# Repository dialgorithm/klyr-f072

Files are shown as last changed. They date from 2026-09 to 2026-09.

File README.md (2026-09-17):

<h1 align="center">
  klyr f072
  <br>
</h1>

<h4 align="center">
    STM32F072CBT6 dev board with usb c
</h4>

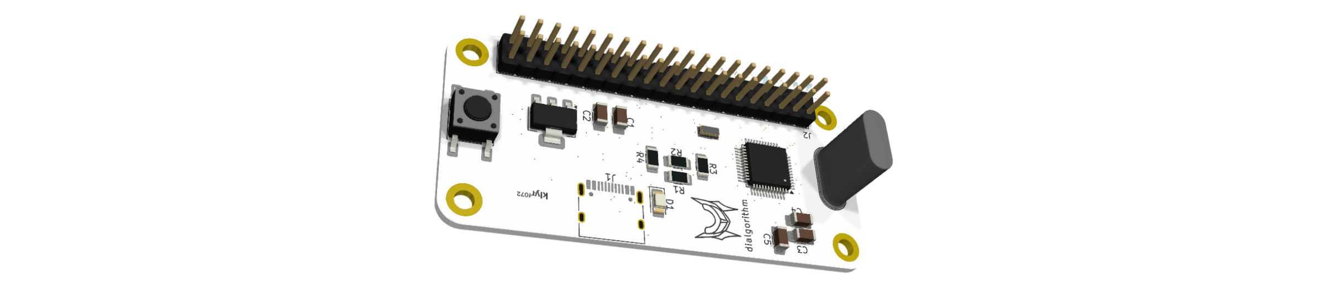
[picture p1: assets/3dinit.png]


## Schematics + PCB

| Schematic | PCB |
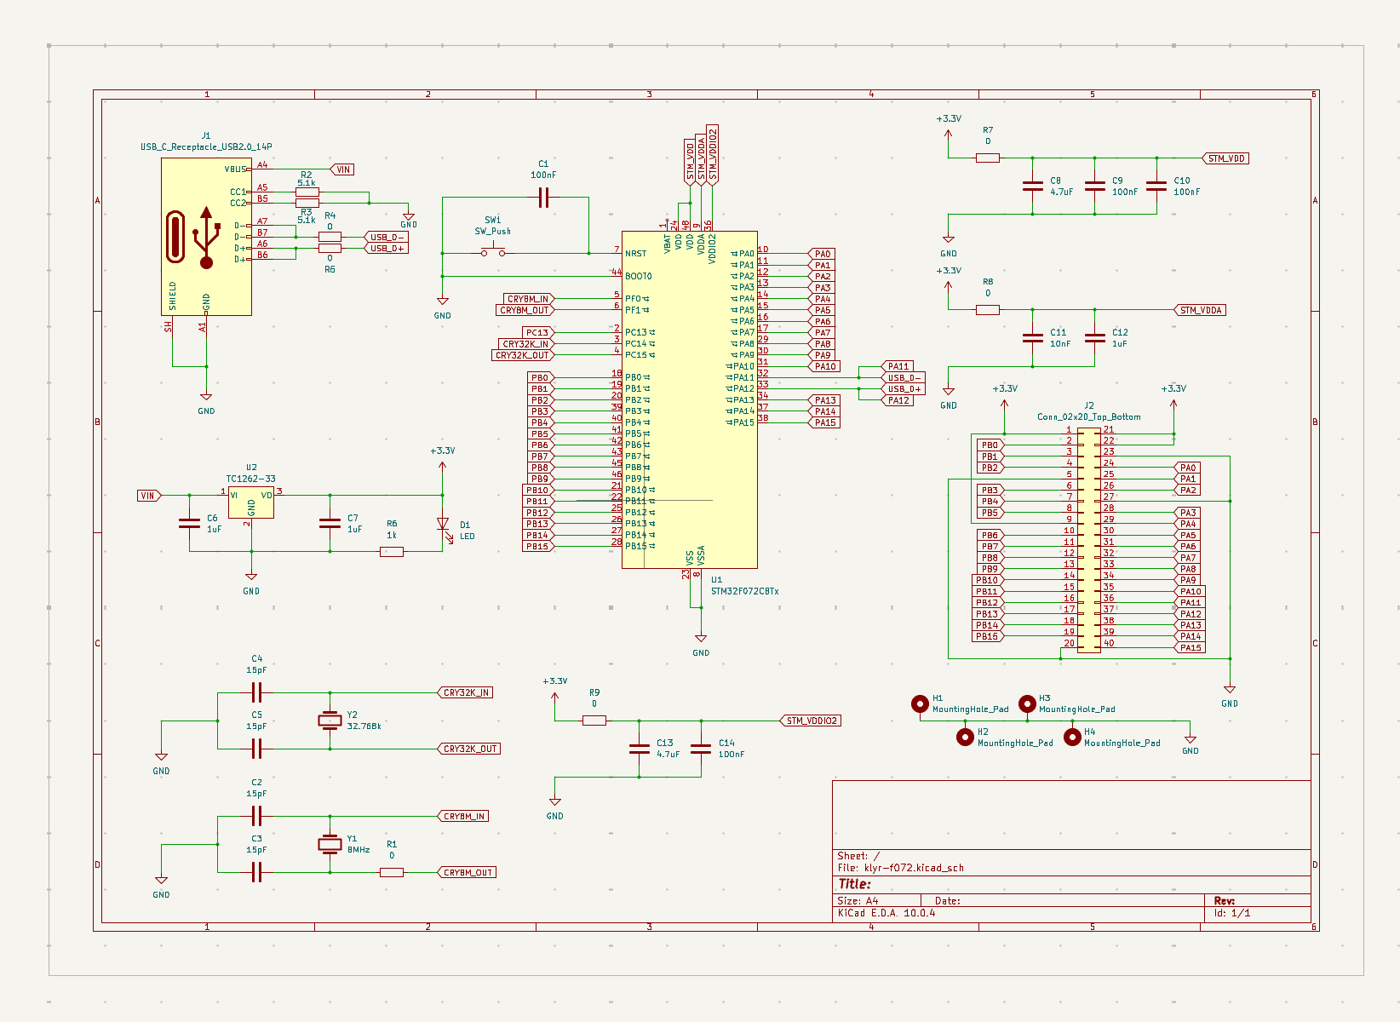
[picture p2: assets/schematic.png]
schematic
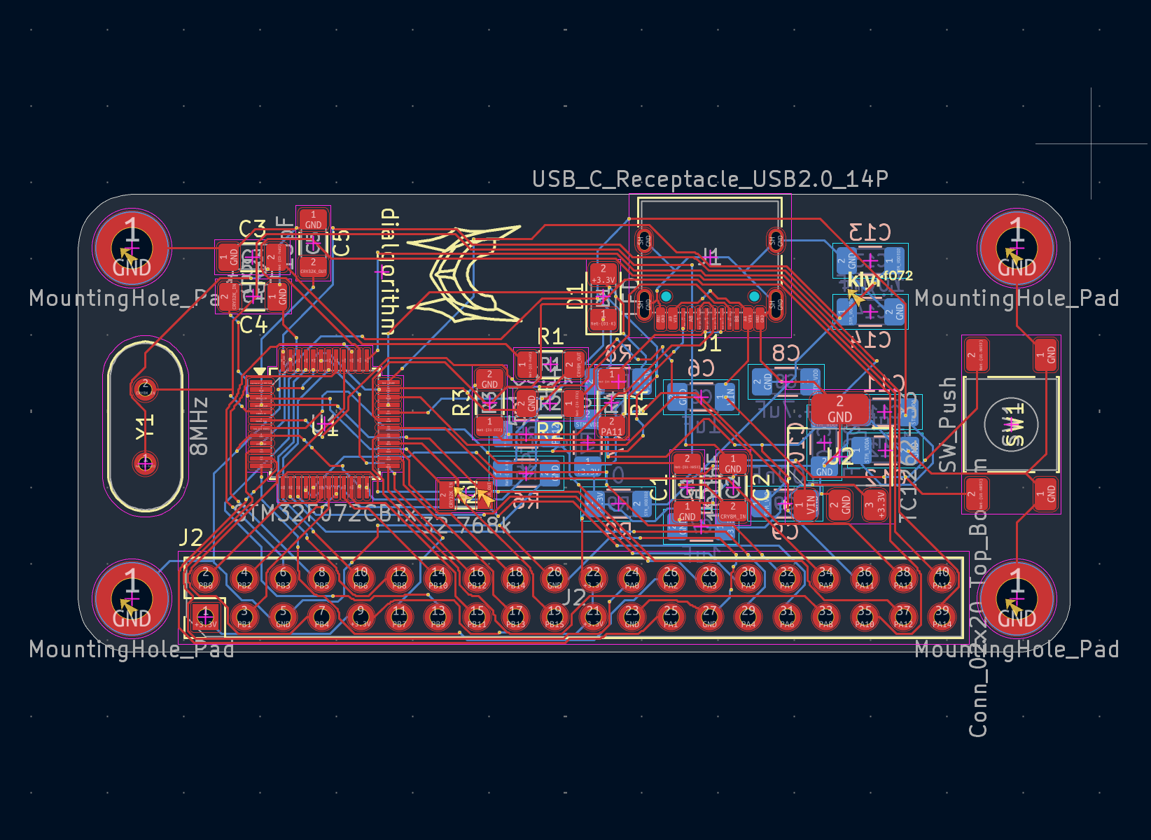
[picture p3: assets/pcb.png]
|  |  |

| top layer | bottom layer |
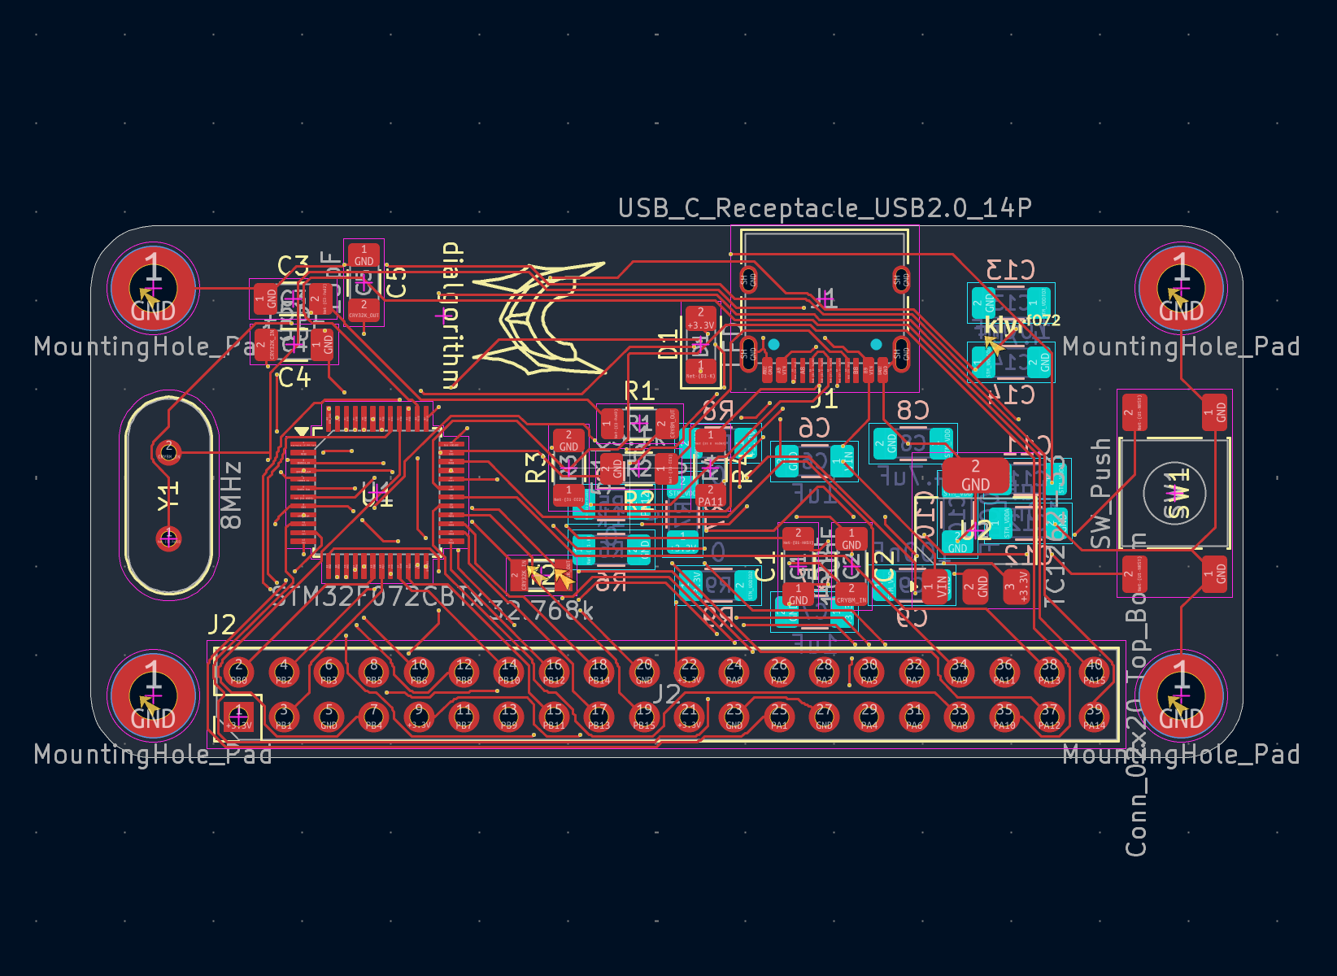
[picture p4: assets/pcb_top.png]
pcb top
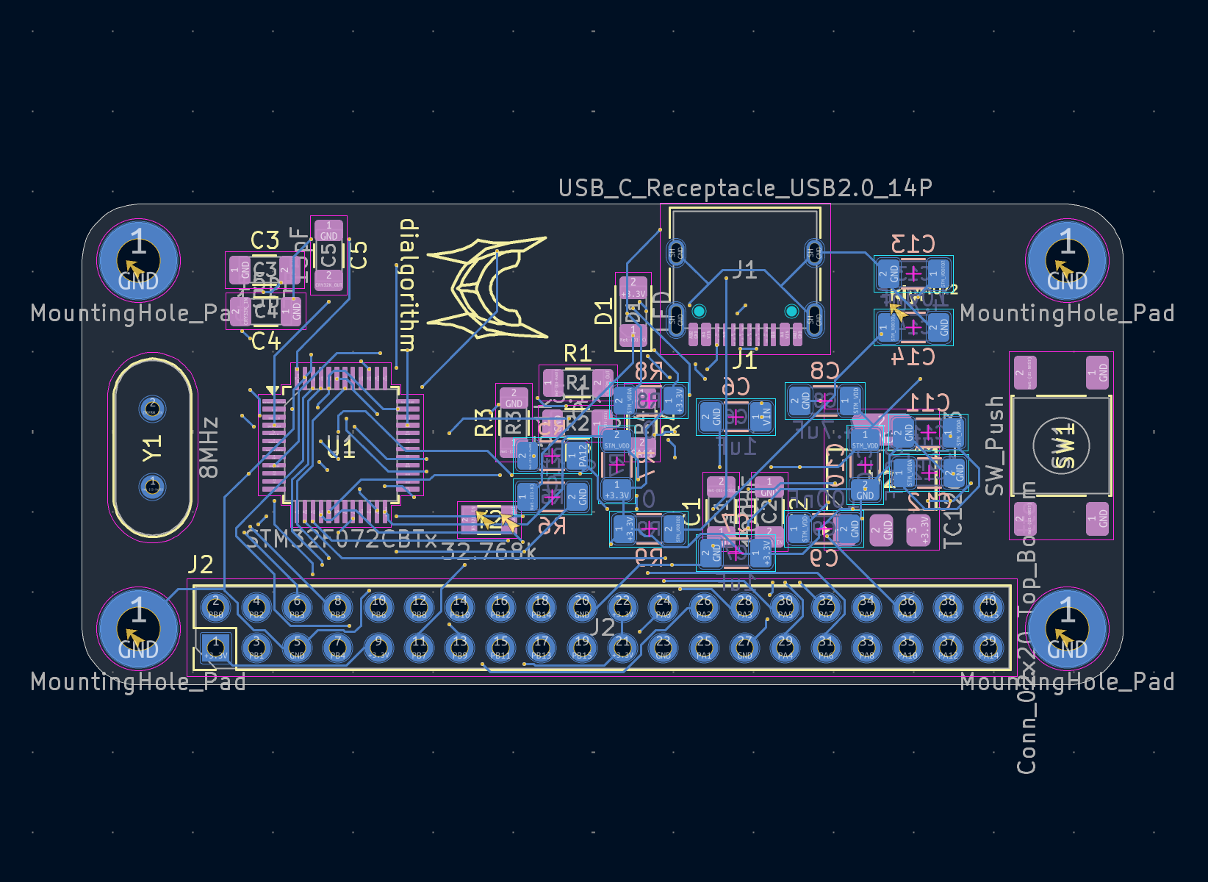
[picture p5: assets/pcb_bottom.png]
pcb bottom
|  |  |

## BOM

the complete bill of materials is available in [`bom.csv`](bom.csv).

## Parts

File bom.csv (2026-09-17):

component | qty | cost | source
PCB | 5 | $11 | https://robu.in/product/online-pcb-manufacturing-service/
100nF 1206 Capacitor | 8 | $1 | https://robu.in/product/grm31cr72e104kw03l-murata-electronics-250v-100nf-x7r-%c2%b110-1206-multilayer-ceramic-capacitors-mlcc-smd-smt-rohs-2/
10nF 1206 Capacitor | 2 | $1 | https://robu.in/product/grm3195c1h103ja01d-murata-electronics-50v-10nf-c0g-%c2%b15-1206-multilayer-ceramic-capacitors-mlcc-smd-smt-rohs-2/
1uF 1206 Capacitor | 6 | $1 | https://robu.in/product/grm31cr71h105ka61l-murata-electronics-50v-1uf-x7r-%c2%b110-1206-multilayer-ceramic-capacitors-mlcc-smd-smt-rohs-2/
4.7uF 1206 Capacitor | 4 | $1 | https://robu.in/product/gcm31cr71c475ka37l-murata-electronics-16v-4-7uf-x7r-%c2%b110-1206-multilayer-ceramic-capacitors-mlcc-smd-smt-rohs-2/
15pF 1206 Capacitor | 8 | $1 | https://robu.in/product/c1206c150j5gacauto-kemet-smd-multilayer-ceramic-capacitor-15-pf-50-v-1206-3216-metric-%c2%b1-5-c0g-np0/
1206 LED | 4 | $1 | https://robu.in/product/xl-3216ubc-fb-xinglight-reverse-mount-blue-120-1206-led-indication-discrete-rohs/
USB C Receptacle HRO type 16pin | 2 | $2 | https://robu.in/product/type-c-31-m-12-hroparts-5a-1-16p-female-type-c-smd-usb-connectors-rohs/
2x20 Pin Header | 2 | $1 | https://robu.in/product/2-54mm-2x20-pin-female-double-row-header-strip-pack-of-5/
0ohm 1206 Resistor | 12 | $1 | https://robu.in/product/rc1206jr-070rl-yageo-zero-ohm-resistor-jumper-1206-3216-metric-thick-film-250-mw-2-a-surface-mount-device-pack-of-10/
5.1k 1206 Resistor | 4 | $1 | https://robu.in/product/1206w4f5101t5e-uniohm-royal-ohm-250mw-thick-film-resistors-200v-%c2%b1100ppm-%e2%84%83-%c2%b11-5-1k%cf%89-1206-chip-resistor-surface-m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
1k 1206 Resistor | 2 | $1 | https://robu.in/product/ac1206fr-071kl-yageo-res-thick-film-1206-1k-ohm-1-0-25w1-4w-%c2%b1100ppm-c-pad-smd-t-r-automotive-aec-q200/
TL3301N Switch | 2 | $3.2 | https://www.lioncircuits.com/parts/TL3301NF160QG
STM32F072CBT6 IC | 2 | $27 | https://www.lioncircuits.com/parts/STM32F072CBT6
TC1262-3.3VDBTR IC | 2 | $4.5 | https://robu.in/product/tc1262-3-3vdbtr-microchip-fixed-ldo-voltage-regulator-2-7v-to-6v-350mv-dropout-3-3vout-500maout-sot-223-3/
8MHz crystal | 2 | $1 | https://robu.in/product/hc49-s-8mhz-crystal-oscillator-pack-of-5/
32.768k crystal | 2 | $1 | https://sharvielectronics.com/product/sf-3215-32-768khz-12-5pf-20ppm-smd-quartz-crystal-sf32k32768d31t-12-5b/
Flux | 1 | $4.5 | https://www.amazon.in/SCHOFIC-No-clean-Halogen-free-Soldering-Electronics/dp/B0F4RKKKX7
Solder Paste (smd) | 1 | $9.5 | https://www.amazon.in/DHRUVPRO-Assembly-Sn63-Pb37-Soldering/dp/B0BBHF1P49/
Solder Wire | 1 | $4.5 | https://www.amazon.in/GREENARTZ-Soldering-core-Aluminium-Copper/dp/B0BNLQX91R
Total | - | $83.5 | -

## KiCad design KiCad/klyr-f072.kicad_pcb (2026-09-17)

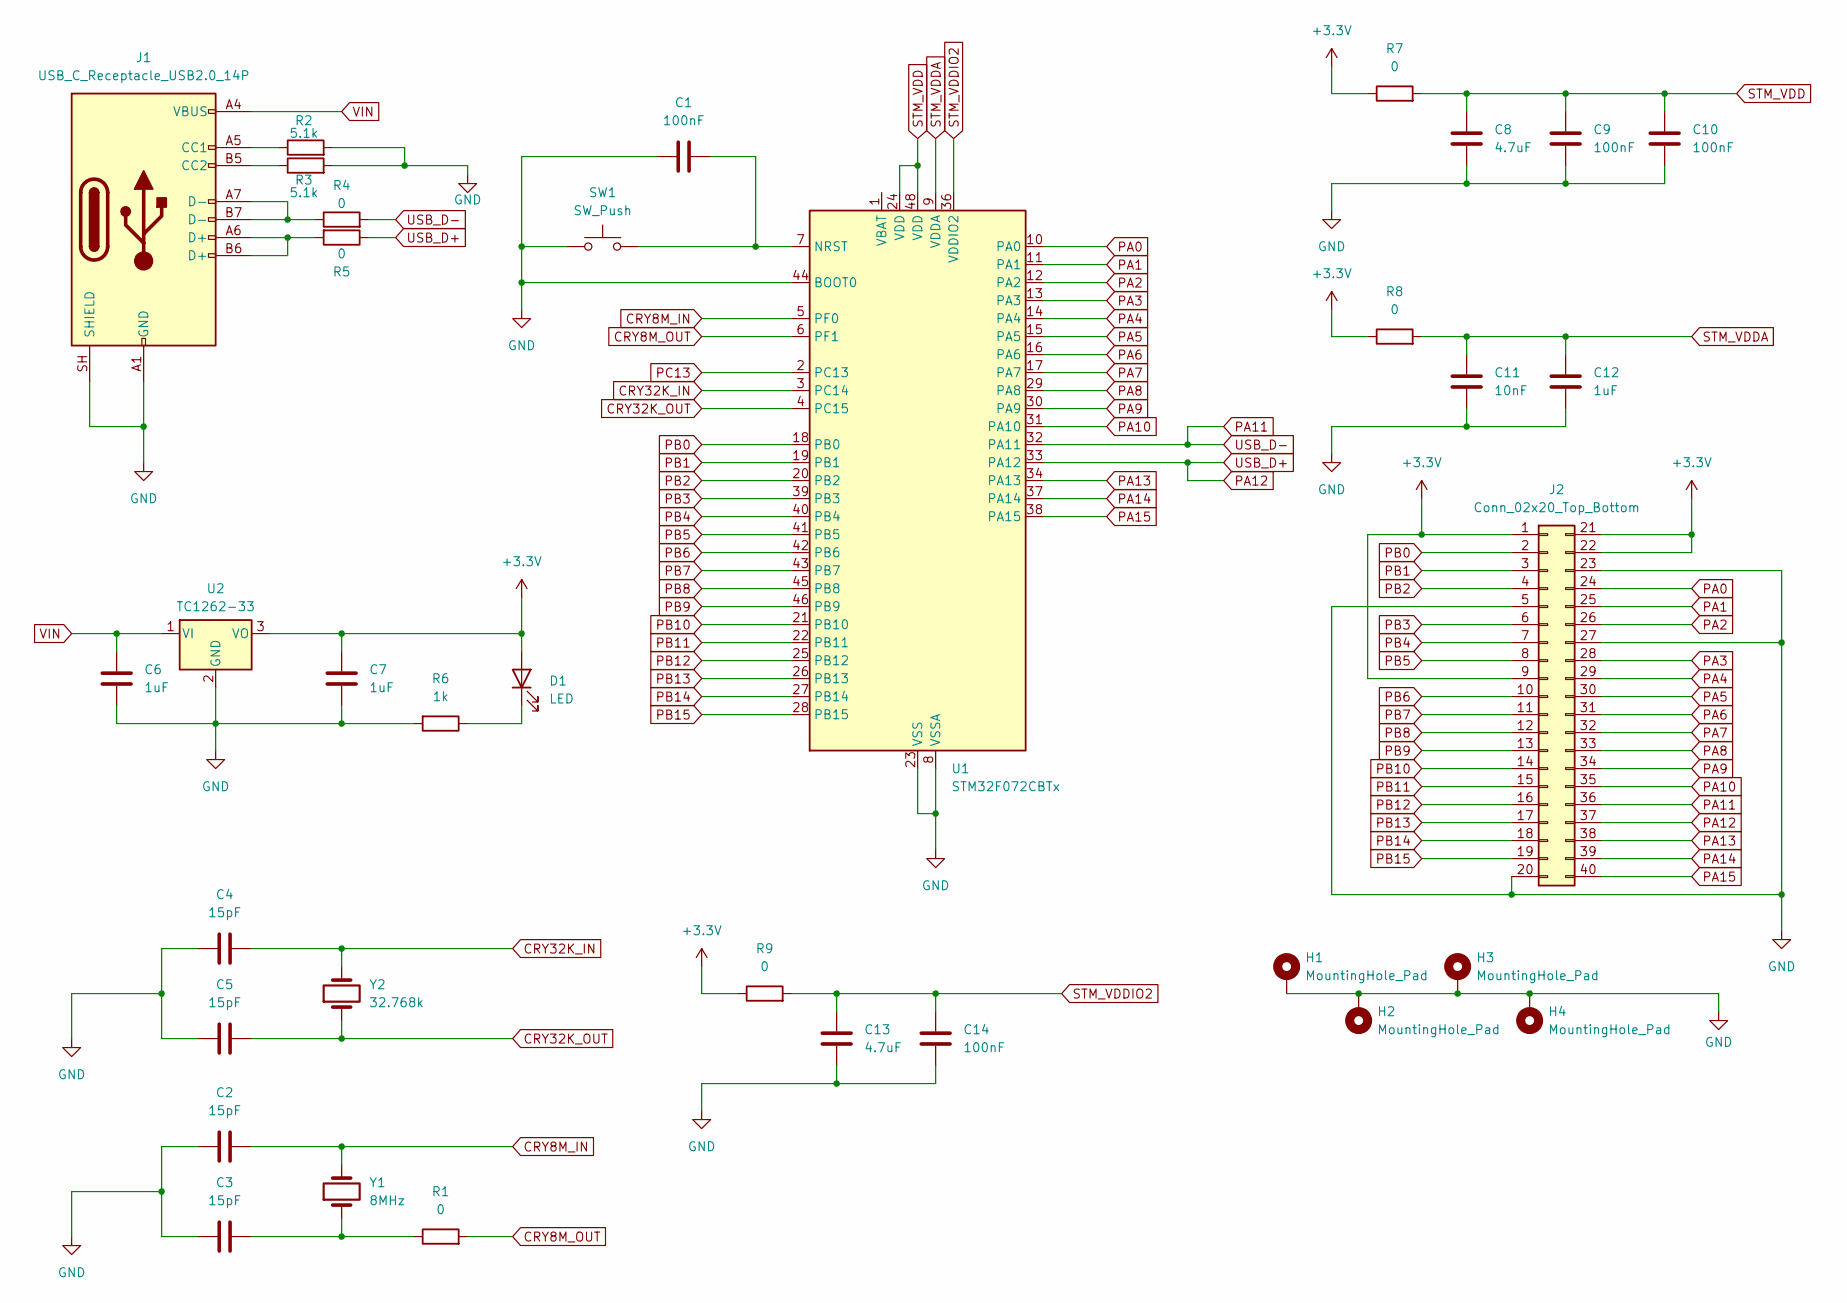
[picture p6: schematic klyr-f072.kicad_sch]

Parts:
C1, C9, C10, C14: 100nF; C_1206_3216Metric_Pad1.33x1.80mm_HandSolder
C2, C3, C4, C5: 15pF; C_1206_3216Metric_Pad1.33x1.80mm_HandSolder
C6, C7, C12: 1uF; C_1206_3216Metric_Pad1.33x1.80mm_HandSolder
C8, C13: 4.7uF; C_1206_3216Metric_Pad1.33x1.80mm_HandSolder
C11: 10nF; C_1206_3216Metric_Pad1.33x1.80mm_HandSolder
D1: LED; LED_1206_3216Metric_Pad1.42x1.75mm_HandSolder
H1, H2, H3, H4: MountingHole_Pad; MountingHole_2.7mm_M2.5_DIN965_Pad
J1: USB_C_Receptacle_USB2.0_14P; USB_C_Receptacle_HRO_TYPE-C-31-M-12
J2: Conn_02x20_Top_Bottom; PinHeader_2x20_P2.54mm_Vertical
R1, R4, R5, R7, R8, R9: 0; R_1206_3216Metric_Pad1.30x1.75mm_HandSolder
R2, R3: 5.1k; R_1206_3216Metric_Pad1.30x1.75mm_HandSolder
R6: 1k; R_1206_3216Metric_Pad1.30x1.75mm_HandSolder
SW1: SW_Push; SW_Push_1P1T_NO_E-Switch_TL3301NxxxxxG
U1: STM32F072CBTx; LQFP-48_7x7mm_P0.5mm
U2: TC1262-33; SOT-223-3_TabPin2
Y1: 8MHz; Crystal_HC49-U_Vertical
Y2: 32.768k; Crystal_SMD_3215-2Pin_3.2x1.5mm

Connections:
+3.3V: C7.1, D1.2 (A), J2.1, J2.9, J2.21, J2.22, R7.1, R8.1, R9.1, U2.3 (VO)
CRY8M_IN: C2.2, U1.5 (PF0), Y1.2
CRY8M_OUT: R1.2, U1.6 (PF1)
CRY32K_IN: C4.2, U1.3 (PC14), Y2.2
CRY32K_OUT: C5.2, U1.4 (PC15), Y2.1
GND: C1.1, C2.1, C3.1, C4.1, C5.1, C6.2, C7.2, C8.2, C9.2, C10.2, C11.2, C12.2, C13.2, C14.2, H1.1 (1_1), H2.1 (1_1), H3.1 (1_1), H4.1 (1_1), J1.A1 (GND), J1.A12 (GND), J1.B1 (GND), J1.B12 (GND), J1.SH (SHIELD), J2.5, J2.20, J2.23, J2.27, R2.2, R3.2, R6.2, SW1.1, U1.8 (VSSA), U1.23 (VSS), U1.35 (VSS), U1.44 (BOOT0), U1.47 (VSS), U2.2 (GND)
unnamed: C3.2, R1.1, Y1.1
unnamed: D1.1 (K), R6.1
unnamed: J1.A5 (CC1), R2.1
unnamed: J1.B5 (CC2), R3.1
unnamed: J1.A6 (D+), J1.B6 (D+), R5.2
unnamed: J1.A7 (D-), J1.B7 (D-), R4.1
unnamed: C1.2, SW1.2, U1.7 (NRST)
PA0: J2.24, U1.10 (PA0)
PA1: J2.25, U1.11 (PA1)
PA2: J2.26, U1.12 (PA2)
PA3: J2.28, U1.13 (PA3)
PA4: J2.29, U1.14 (PA4)
PA5: J2.30, U1.15 (PA5)
PA6: J2.31, U1.16 (PA6)
PA7: J2.32, U1.17 (PA7)
PA8: J2.33, U1.29 (PA8)
PA9: J2.34, U1.30 (PA9)
PA10: J2.35, U1.31 (PA10)
PA11: J2.36, R4.2, U1.32 (PA11)
PA12: J2.37, R5.1, U1.33 (PA12)
PA13: J2.38, U1.34 (PA13)
PA14: J2.39, U1.37 (PA14)
PA15: J2.40, U1.38 (PA15)
PB0: J2.2, U1.18 (PB0)
PB1: J2.3, U1.19 (PB1)
PB2: J2.4, U1.20 (PB2)
PB3: J2.6, U1.39 (PB3)
PB4: J2.7, U1.40 (PB4)
PB5: J2.8, U1.41 (PB5)
PB6: J2.10, U1.42 (PB6)
PB7: J2.11, U1.43 (PB7)
PB8: J2.12, U1.45 (PB8)
PB9: J2.13, U1.46 (PB9)
PB10: J2.14, U1.21 (PB10)
PB11: J2.15, U1.22 (PB11)
PB12: J2.16, U1.25 (PB12)
PB13: J2.17, U1.26 (PB13)
PB14: J2.18, U1.27 (PB14)
PB15: J2.19, U1.28 (PB15)
PC13: U1.2 (PC13)
STM_VDD: C8.1, C9.1, C10.1, R7.2, U1.24 (VDD), U1.48 (VDD)
STM_VDDA: C11.1, C12.1, R8.2, U1.9 (VDDA)
STM_VDDIO2: C13.1, C14.1, R9.2, U1.36 (VDDIO2)
VIN: C6.1, J1.A4 (VBUS), J1.A9 (VBUS), J1.B4 (VBUS), J1.B9 (VBUS), U2.1 (VI)

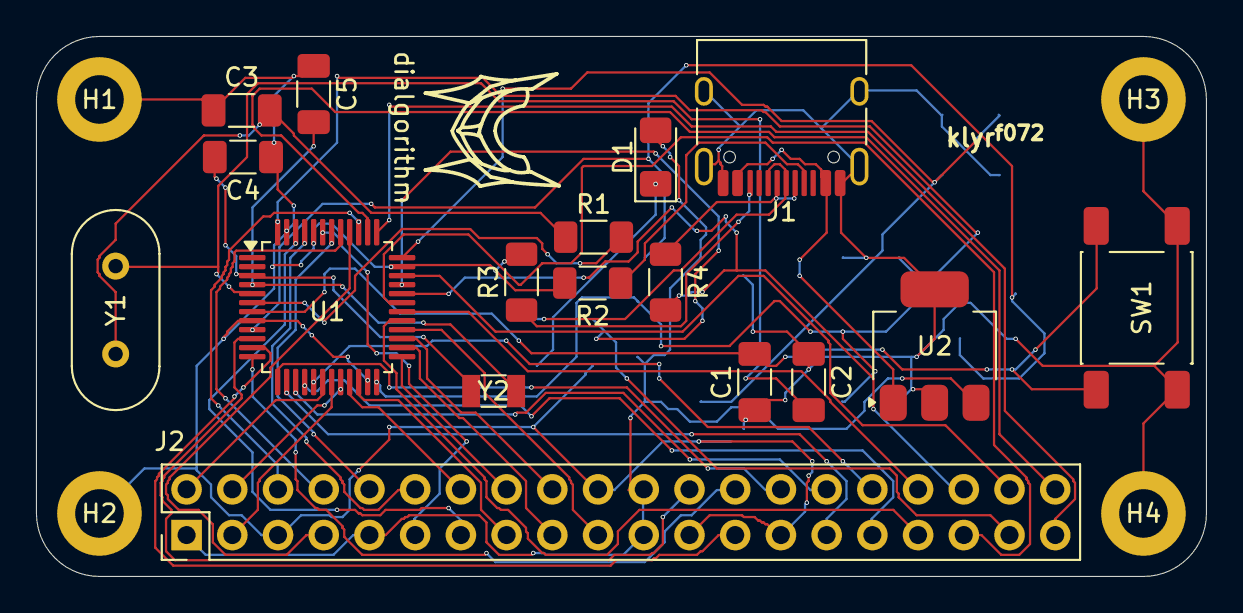
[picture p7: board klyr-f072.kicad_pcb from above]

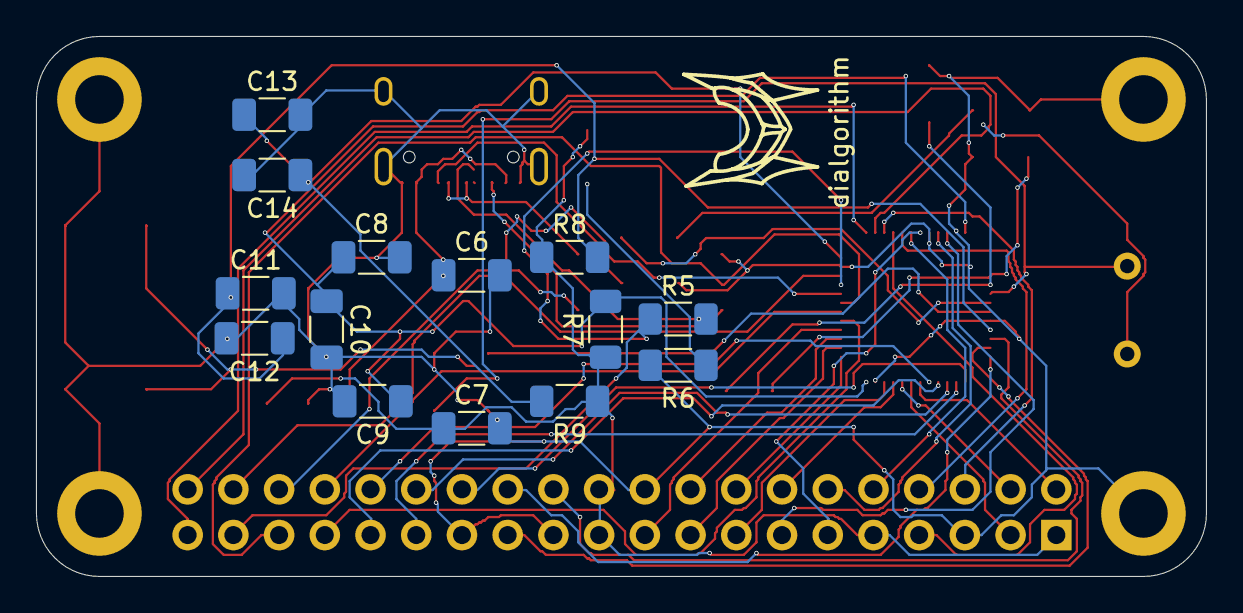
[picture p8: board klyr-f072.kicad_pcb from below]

Board: 2 copper layers, 65.0 x 30.0 mm, 37 parts (15 on the bottom side), 49 nets.

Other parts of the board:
dialgorithm: dialgorithm
dialgorithm#2: dialgorithm
